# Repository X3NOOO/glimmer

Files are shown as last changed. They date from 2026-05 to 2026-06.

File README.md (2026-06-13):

# Glimmer
Glimmer is an [WLED](https://github.com/wled/WLED) controller board. It supports all the most common LED strip voltages over 6.3mm jack and 5V over USB-C, audio reactivity, IR control, and driving two separate data channels at once.

<details>
<summary>Photos</summary>

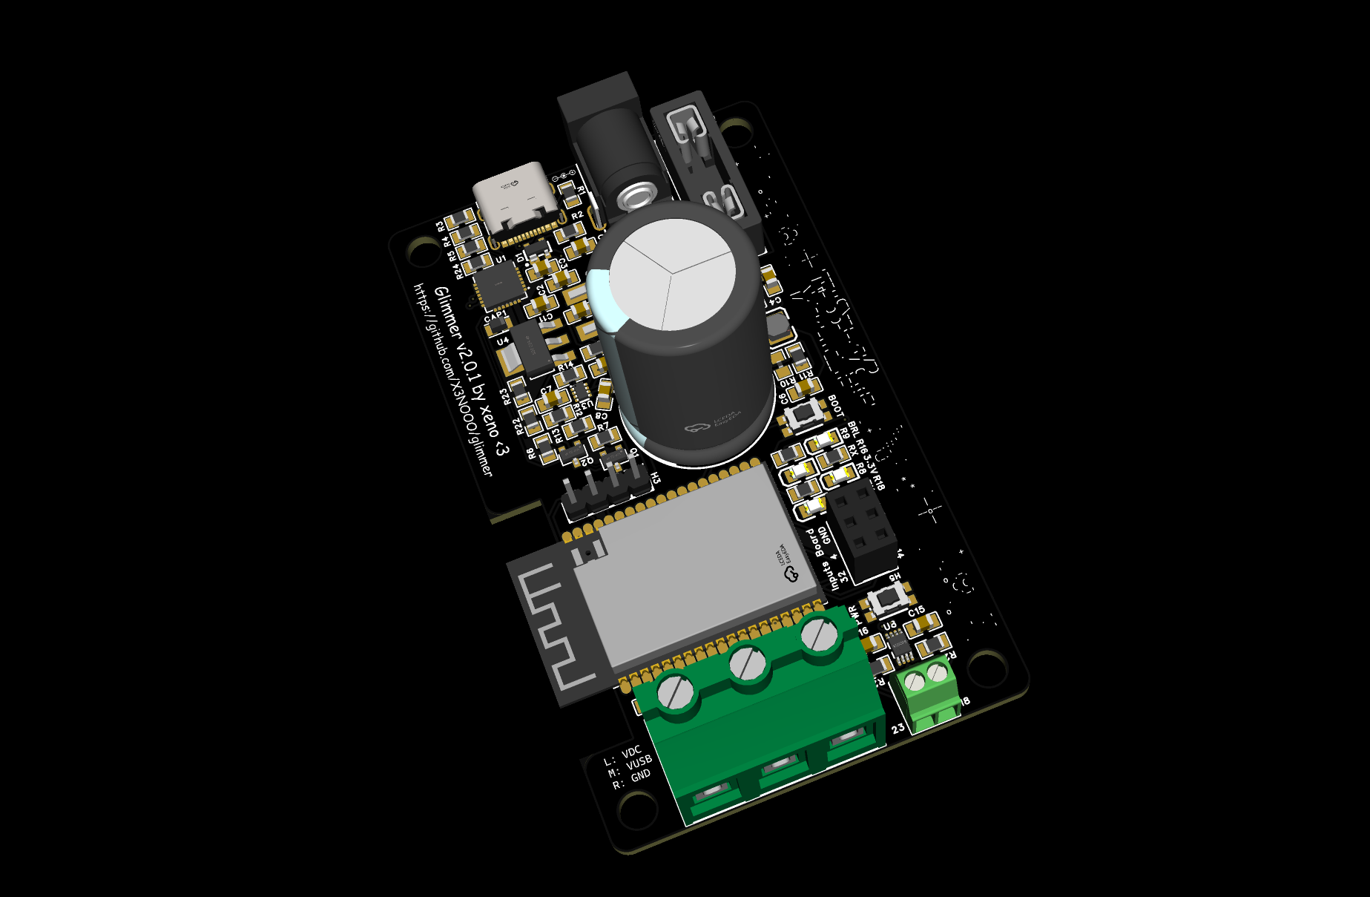
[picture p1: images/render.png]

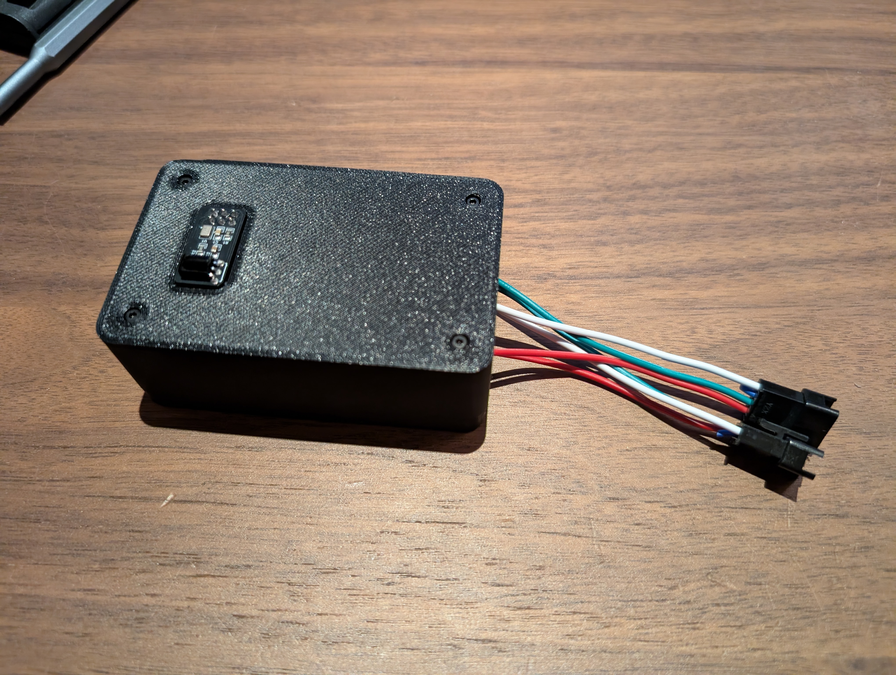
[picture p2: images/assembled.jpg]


[schematics.pdf](/images/schematics.pdf)

</details>

## OSHWLab Stars 2026
The project had to be remade in EasyEDA in order to be submitted to the OSHWLab Stars competition. I'm not the biggest fan of the program, but it is what it is.

If you like the project feel free to check out it's OSHWLab page and maybe even leave a like if you're generous like that.

Link to the project over there: https://oshwlab.com/x3no/project_caxlifbu

## Software
The controller is meant to run under WLED. Check their docs for info about configuration and flashing.
Website: https://kno.wled.ge/
Github: https://github.com/WLED/WLED

There is an USB autoflashing circuitry present on the board, but you can use the UART port as well. If you do want to do it you should desolder the 0-ohm R22 and R22 resistors - they bridge the USB-UART controller with the ESP32.

If you want to use WLED-MM a platformio compilation environment is available [here](https://gist.github.com/X3NOOO/2119d469b6a600acc29e1caa4ec98841).

### UART LEDs

If the TX/RX LEDs are not flashing when talking with the board via USB your CP2102N didn't come with TXT and RXT enabled by default. You can change that using the [Simplicity Studio 5](https://www.silabs.com/software-and-tools/simplicity-studio/simplicity-studio-version-5). Download it, connect the board, and change the GPIO settings from GPIO to TXT and RXT. Doing this is not neccesary for the board to work though.

## Usage
Flashed your board with WLED? Good, now it's the time to wire it up. The first thing to do is to place a properly rated fuse into the fuse holder. The [3557-2 fuseholder](https://www.keyelco.com/userAssets/file/K75p47.pdf) takes both standard and mini automotive fuses. You can calculate the fuse value using the WLED calculator. The big screw terminal is responsible for power delivery. When holding your controller with the USB port up and facing you:
- The first hole is VDC, it's the barrel jack input, except it's fused via the fuse you just put in.
- The second hole is VUSB, it's the same power your USB port supplies. There is an 2A polyfuse placed on it's line, so that's the limit on the power you can pull through it.
- The third hole is GND.

Then, there is the smaller screw terminal. It is used to communicate with your LEDs and houses the data lines. Both of them are levelshifted to 5V. The one on the left is mapped to your ESP32's GPIO23 and the right one is GPIO18.

Now you connect the inputs board. Place some doublesided tape on the back of it and secure it in the cutout on the shell. Wire the connector 1:1, you can check the pinout if you're not sure if you're doing it right.

## Case
The .stl files of the enclosure are available in the Releases tab.

## Pricing
Prices at JLCPCB.

### Controller
- $160: Price for 2 assembled and 3 bare PCBs. All in black.
- $100: Price for 2 assembled and 3 bare PCBs w/o the ESP32 which forces you to pick standard assembly.
- $30: Price for 2+3 with most of the extended components excluded if you're willing to source and solder them yourself.

### Inputs board
Header is not soldered in any of the variants.
- $70: 2 assembled and 3 bare ones.
- $20: 2 assembled and 3 bare ones w/o the microphone as it forces standard assembly.

### Shell
- Up to $10: 1 bottom + 1 top. 

### Additional
- 4x >33mm M2 screws.
- 4x M2 threaded M2 insert nuts. Length=2mm, OD=4mm.
- A bit of double sided tape if your Inputs Board doesn't hold in place.

## Get it
All the files necessary to get the board made at JLCPCB are available in the Releases tab. They include all the components, so you can expect a to see a high price if you use them as they are. You can tweak the assembly components after uploading the BOM to the website to lower the price.

## IMPORTANT
I am not an engineer - the PCB works, but I cannot guarantee it will not burn your house down. I do not take any responsibility for y'all being silly.

## Sidenotes
- Thank you to the (unfortunately dead) [yawl controller](https://github.com/lizardsystems/yawl-controller) project - I stole your levelshifter.

- Thank you to the creators of the [OSHWLab Stars](https://oshwlab.com/activities/stars2026) competition for making it possible to get this board manufactured in a reasonable price.

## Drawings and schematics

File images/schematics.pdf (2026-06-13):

# Power Input

## Barrel jack

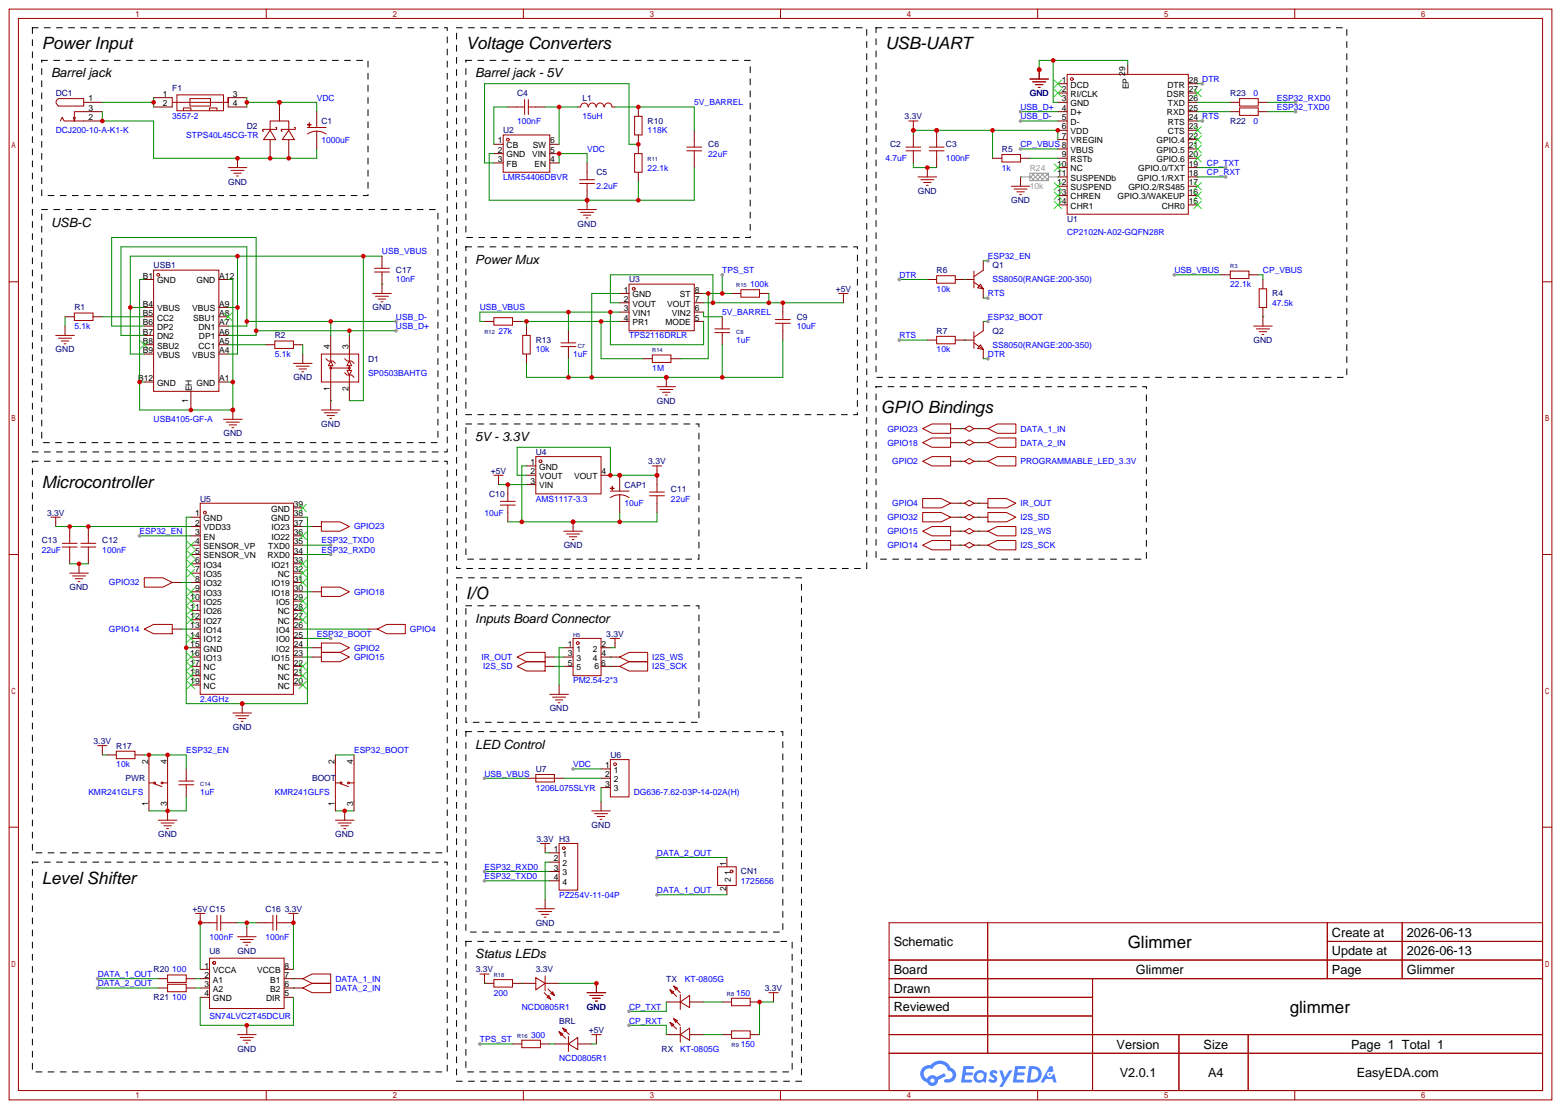
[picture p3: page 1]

Schematic | Glimmer | Create at | 2026-06-13

Update at | 2026-06-13

Board | Glimmer | Page | Glimmer
Drawn | | glimmer
Reviewed

Version | Size | Page 1 Total 1
V2.0.1 | A4 | EasyEDA.com

# Connector

# IR Receiver

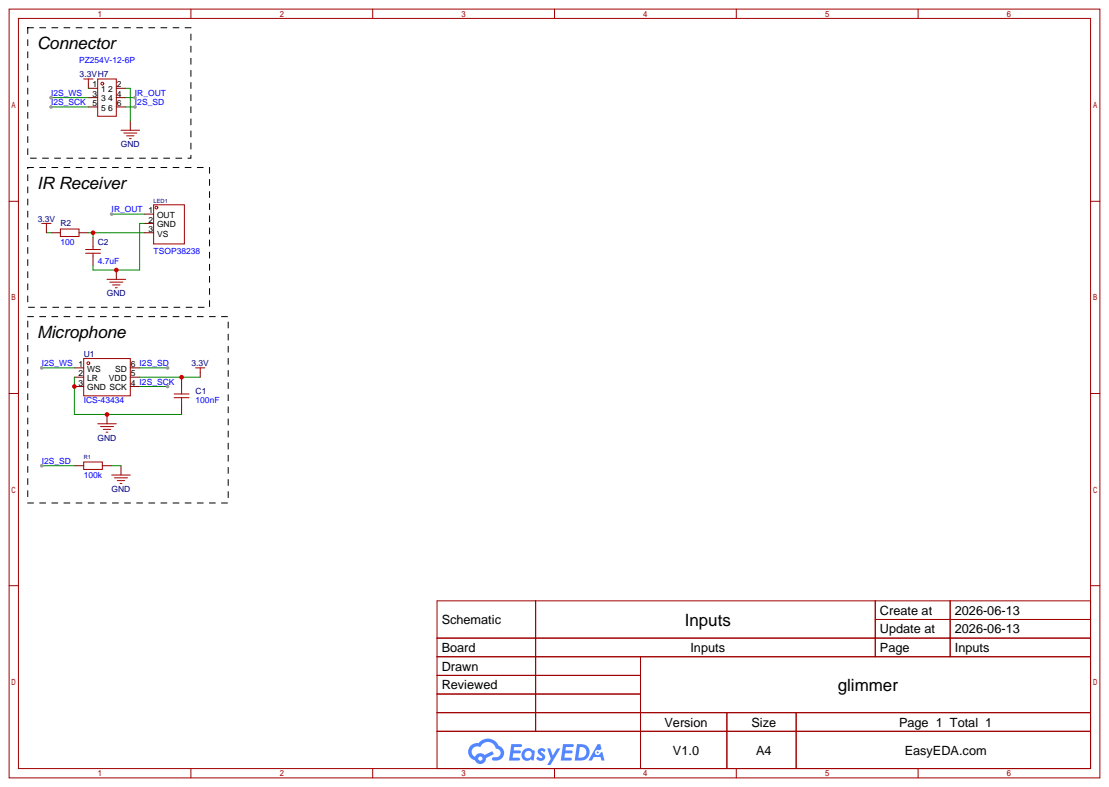
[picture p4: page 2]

Schematic | Inputs | Create at | 2026-06-13

Update at | 2026-06-13

Board | Inputs | Page | Inputs
Drawn | | glimmer
Reviewed

Version | Size | Page 1 Total 1
V1.0 | A4 | EasyEDA.com

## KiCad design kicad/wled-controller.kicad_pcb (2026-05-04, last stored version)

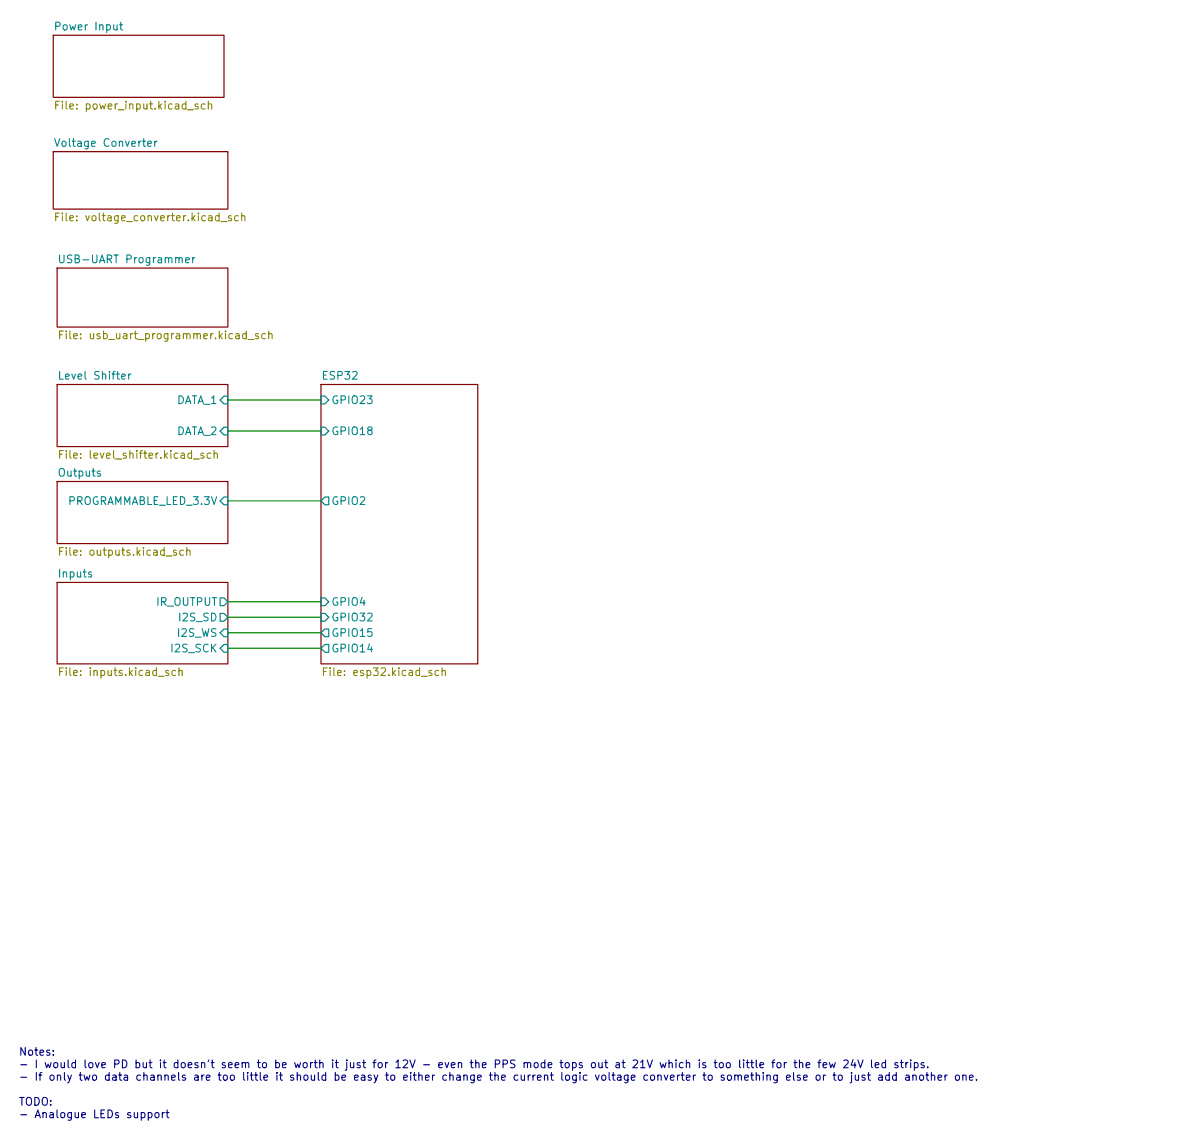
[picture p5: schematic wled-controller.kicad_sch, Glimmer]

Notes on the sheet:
Notes: - I would love PD but it doesn't seem to be worth it just for 12V - even the PPS mode tops out at 21V which is too little for the few 24V led strips. - If only two data channels are too little it should be easy to either change the current logic voltage converter to something else or to just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

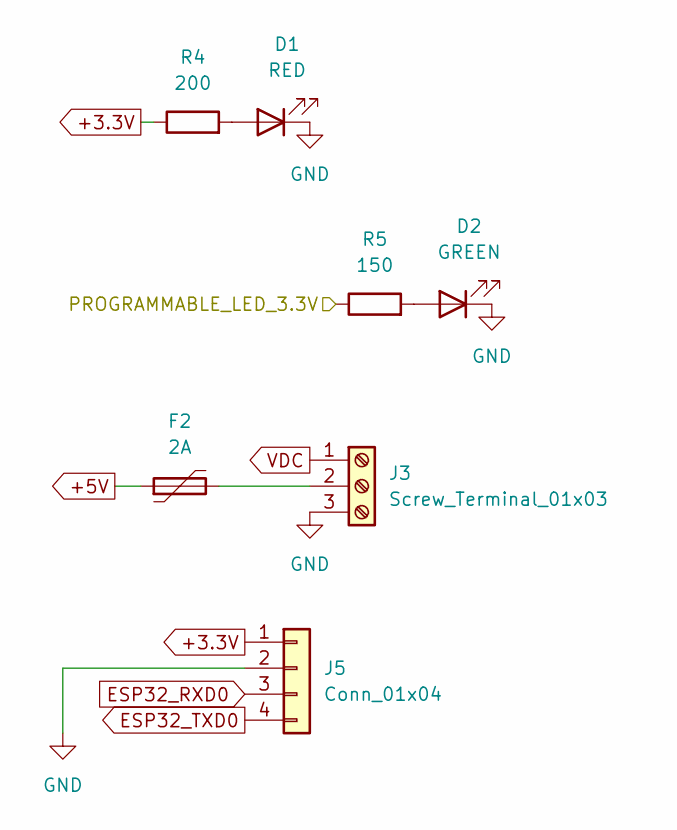
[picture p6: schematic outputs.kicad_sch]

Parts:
D1: RED; LED_0805_2012Metric_Pad1.15x1.40mm_HandSolder
D2: GREEN; LED_0805_2012Metric_Pad1.15x1.40mm_HandSolder
F2: 2A; 1206L075SLYR
J3: Screw_Terminal_01x03; TerminalBlock_TE_282834-3_1x03_P2.54mm_Horizontal
J5: Conn_01x04; NS-Tech_Grove_1x04_P2mm_Vertical
R4: 200; R_0805_2012Metric_Pad1.20x1.40mm_HandSolder
R5: 150; R_0805_2012Metric_Pad1.20x1.40mm_HandSolder

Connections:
+3.3V: J5.1, R4.1; also elsewhere on the board
+5V: F2.1; also elsewhere on the board
/ESP32/GPIO2: R5.1; also elsewhere on the board
ESP32_RXD0: J5.3; also elsewhere on the board
ESP32_TXD0: J5.4; also elsewhere on the board
GND: D1.1 (K), D2.1 (K), J3.3, J5.2; also elsewhere on the board
unnamed: D1.2 (A), R4.2
unnamed: D2.2 (A), R5.2
unnamed: F2.2, J3.2
VDC: J3.1; also elsewhere on the board

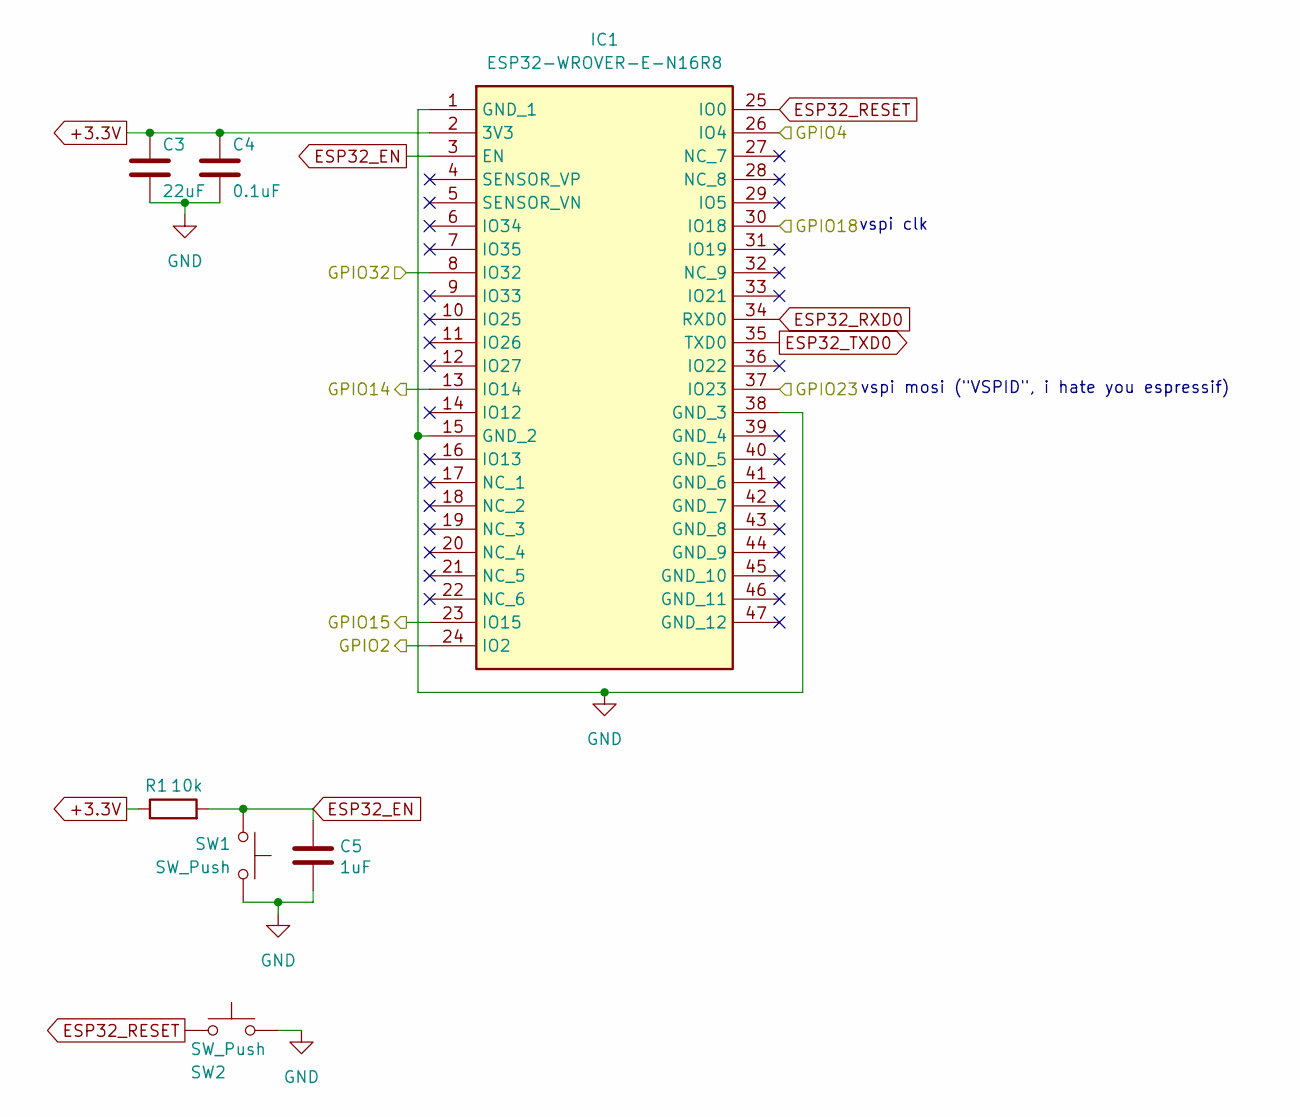
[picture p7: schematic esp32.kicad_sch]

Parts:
C3: 22uF; C_0805_2012Metric_Pad1.18x1.45mm_HandSolder
C4: 0.1uF; C_0805_2012Metric_Pad1.18x1.45mm_HandSolder
C5: 1uF; C_0805_2012Metric_Pad1.18x1.45mm_HandSolder
IC1: ESP32-WROVER-E-N16R8; ESP32WROVEREN16R8; Manufacturer_Part_Number ESP32-WROVER-E-N16R8; Mouser Part Number 356-ESP32WRVE22864PC
R1: 10k; R_0805_2012Metric_Pad1.20x1.40mm_HandSolder
SW1, SW2: SW_Push; SW_Push_1P1T_NO_CK_KMR2

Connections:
+3.3V: C3.1, C4.1, IC1.2 (3V3), R1.1; also elsewhere on the board
/ESP32/GPIO2: IC1.24 (IO2); also elsewhere on the board
/ESP32/GPIO4: IC1.26 (IO4); also elsewhere on the board
/ESP32/GPIO14: IC1.13 (IO14); also elsewhere on the board
/ESP32/GPIO15: IC1.23 (IO15); also elsewhere on the board
/ESP32/GPIO18: IC1.30 (IO18); also elsewhere on the board
/ESP32/GPIO23: IC1.37 (IO23); also elsewhere on the board
/ESP32/GPIO32: IC1.8 (IO32); also elsewhere on the board
ESP32_EN: C5.1, IC1.3 (EN), R1.2, SW1.1; also elsewhere on the board
ESP32_RESET: IC1.25 (IO0), SW2.1; also elsewhere on the board
ESP32_RXD0: IC1.34 (RXD0); also elsewhere on the board
ESP32_TXD0: IC1.35 (TXD0); also elsewhere on the board
GND: C3.2, C4.2, C5.2, IC1.1 (GND_1), IC1.15 (GND_2), IC1.38 (GND_3), SW1.2, SW2.2; also elsewhere on the board

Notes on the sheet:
vspi mosi ("VSPID", i hate you espressif)
vspi clk

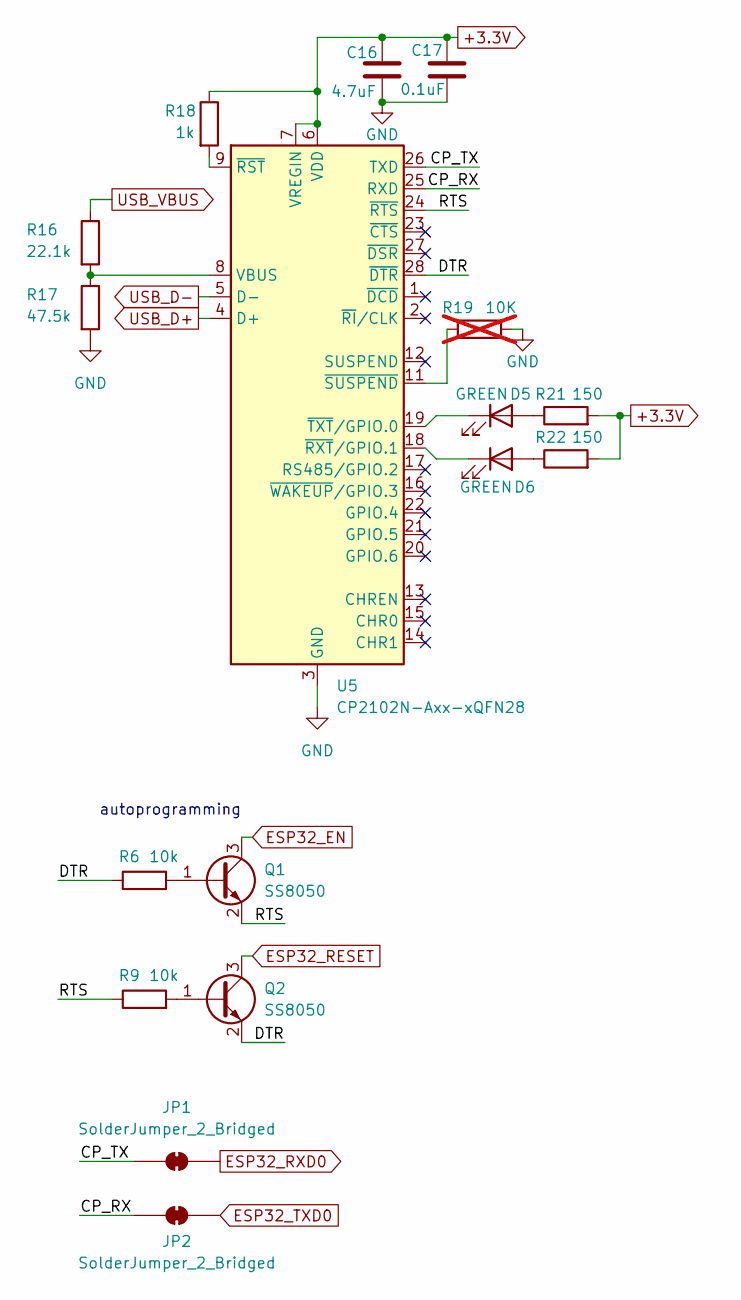
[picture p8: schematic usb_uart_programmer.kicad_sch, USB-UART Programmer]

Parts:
C16: 4.7uF; C_0805_2012Metric_Pad1.18x1.45mm_HandSolder
C17: 0.1uF; C_0805_2012Metric_Pad1.18x1.45mm_HandSolder
D5, D6: GREEN; LED_0805_2012Metric_Pad1.15x1.40mm_HandSolder
JP1, JP2: SolderJumper_2_Bridged; SolderJumper-2_P1.3mm_Open_TrianglePad1.0x1.5mm
Q1, Q2: SS8050; SOT-23
R6, R9: 10k; R_0805_2012Metric_Pad1.20x1.40mm_HandSolder
R16: 22.1k; R_0805_2012Metric_Pad1.20x1.40mm_HandSolder
R17: 47.5k; R_0805_2012Metric_Pad1.20x1.40mm_HandSolder
R18: 1k; R_0805_2012Metric_Pad1.20x1.40mm_HandSolder
R19: 10K; R_0805_2012Metric_Pad1.20x1.40mm_HandSolder; not fitted
R21, R22: 150; R_0805_2012Metric_Pad1.20x1.40mm_HandSolder
U5: CP2102N-Axx-xQFN28; QFN-28-1EP_5x5mm_P0.5mm_EP3.35x3.35mm

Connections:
+3.3V: C16.1, C17.1, R18.1, R21.2, R22.2, U5.6 (VDD), U5.7 (VREGIN); also elsewhere on the board
/USB-UART Programmer/CP_RX: JP2.1 (A), U5.25 (RXD)
/USB-UART Programmer/CP_TX: JP1.1 (A), U5.26 (TXD)
/USB-UART Programmer/DTR: Q2.2 (E), R6.1, U5.28 (~DTR)
/USB-UART Programmer/RTS: Q1.2 (E), R9.1, U5.24 (~RTS)
ESP32_EN: Q1.3 (C); also elsewhere on the board
ESP32_RESET: Q2.3 (C); also elsewhere on the board
ESP32_RXD0: JP1.2 (B); also elsewhere on the board
ESP32_TXD0: JP2.2 (B); also elsewhere on the board
GND: C16.2, C17.2, R17.2, R19.2, U5.3 (GND), U5.29 (GND); also elsewhere on the board
unnamed: D5.2 (A), R21.1
unnamed: D5.1 (K), U5.19 (~TXT/GPIO.0)
unnamed: D6.2 (A), R22.1
unnamed: D6.1 (K), U5.18 (~RXT/GPIO.1)
unnamed: Q1.1 (B), R6.2
unnamed: Q2.1 (B), R9.2
unnamed: R16.2, R17.1, U5.8 (VBUS)
unnamed: R18.2, U5.9 (~RST)
unnamed: R19.1, U5.11 (~SUSPEND)
USB_D+: U5.4 (D+); also elsewhere on the board
USB_D-: U5.5 (D-); also elsewhere on the board
USB_VBUS: R16.1; also elsewhere on the board

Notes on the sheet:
autoprogramming

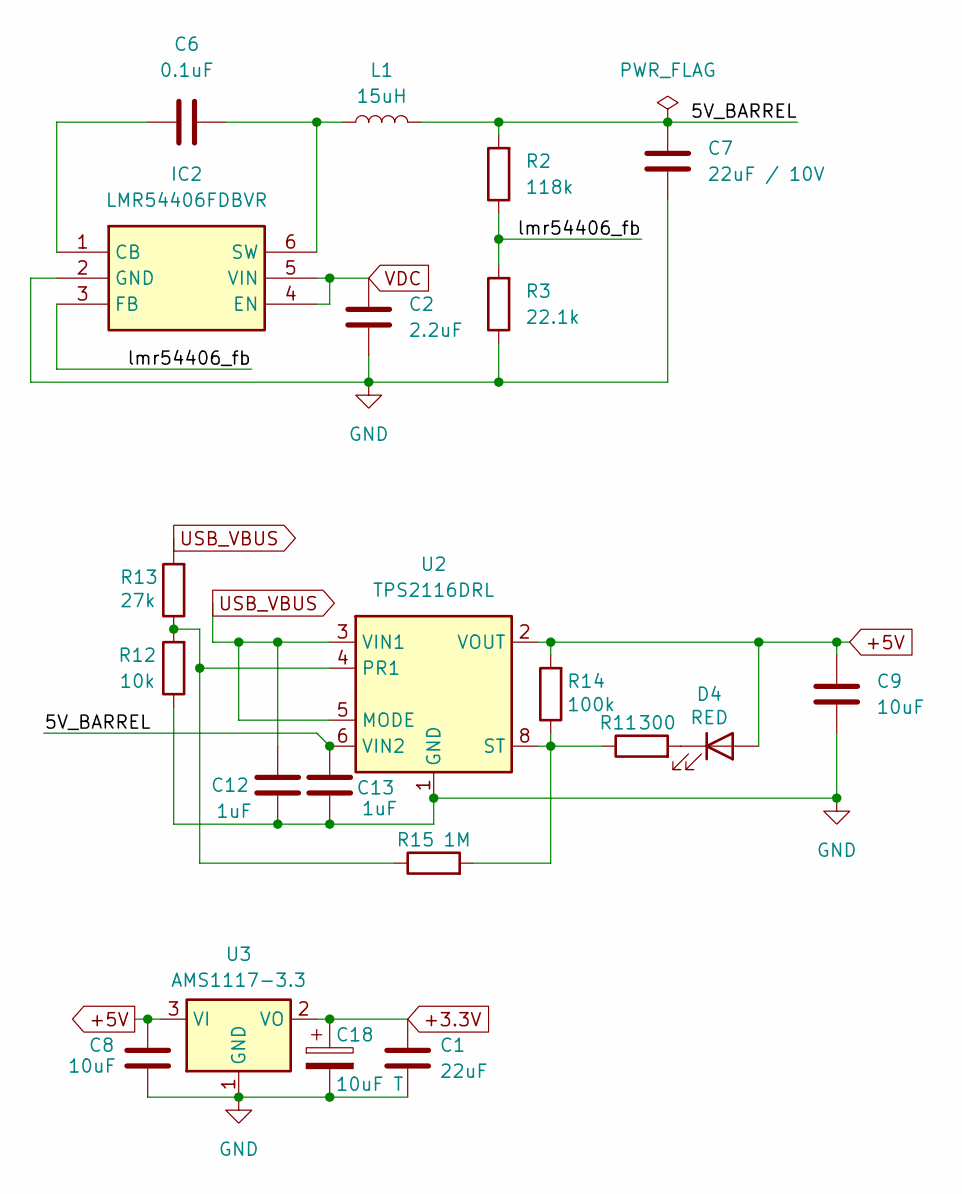
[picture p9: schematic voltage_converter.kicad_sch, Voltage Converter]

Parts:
C1: 22uF; C_0805_2012Metric_Pad1.18x1.45mm_HandSolder
C2: 2.2uF; C_0805_2012Metric_Pad1.18x1.45mm_HandSolder
C6: 0.1uF; C_0805_2012Metric_Pad1.18x1.45mm_HandSolder
C7: 22uF / 10V; C_0805_2012Metric_Pad1.18x1.45mm_HandSolder
C8, C9: 10uF; C_0805_2012Metric_Pad1.18x1.45mm_HandSolder
C12, C13: 1uF; C_0805_2012Metric_Pad1.18x1.45mm_HandSolder
C18: 10uF T; CP_EIA-2012-12_Kemet-R_HandSolder
D4: RED; LED_0805_2012Metric_Pad1.15x1.40mm_HandSolder
IC2: LMR54406FDBVR; SOT95P280X145-6N; Manufacturer_Part_Number LMR54406FDBVR; Mouser Part Number 595-LMR54406FDBVR
L1: 15uH; VLS3015
R2: 118k; R_0805_2012Metric_Pad1.20x1.40mm_HandSolder
R3: 22.1k; R_0805_2012Metric_Pad1.20x1.40mm_HandSolder
R11: 300; R_0805_2012Metric_Pad1.20x1.40mm_HandSolder
R12: 10k; R_0805_2012Metric_Pad1.20x1.40mm_HandSolder
R13: 27k; R_0805_2012Metric_Pad1.20x1.40mm_HandSolder
R14: 100k; R_0805_2012Metric_Pad1.20x1.40mm_HandSolder
R15: 1M; R_0805_2012Metric_Pad1.20x1.40mm_HandSolder
U2: TPS2116DRL; SOT-583-8
U3: AMS1117-3.3; SOT-223-3_TabPin2

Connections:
+3.3V: C1.1, C18.1, U3.2 (VO); also elsewhere on the board
+5V: C8.1, C9.1, D4.2 (A), R14.2, U2.2 (VOUT), U2.7 (VOUT), U3.3 (VI); also elsewhere on the board
/Voltage Converter/5V_BARREL: C7.1, C13.1, L1.2, R2.2, U2.6 (VIN2)
/Voltage Converter/lmr54406_fb: IC2.3 (FB), R2.1, R3.2
GND: C1.2, C2.2, C7.2, C8.2, C9.2, C12.2, C13.2, C18.2, IC2.2 (GND), R3.1, R12.1, U2.1 (GND), U3.1 (GND); also elsewhere on the board
unnamed: D4.1 (K), R11.2
unnamed: C6.1, IC2.1 (CB)
unnamed: C6.2, IC2.6 (SW), L1.1
unnamed: R12.2, R13.1, R15.1, U2.4 (PR1)
unnamed: R11.1, R14.1, R15.2, U2.8 (ST)
USB_VBUS: C12.1, R13.2, U2.3 (VIN1), U2.5 (MODE); also elsewhere on the board
VDC: C2.1, IC2.4 (EN), IC2.5 (VIN); also elsewhere on the board

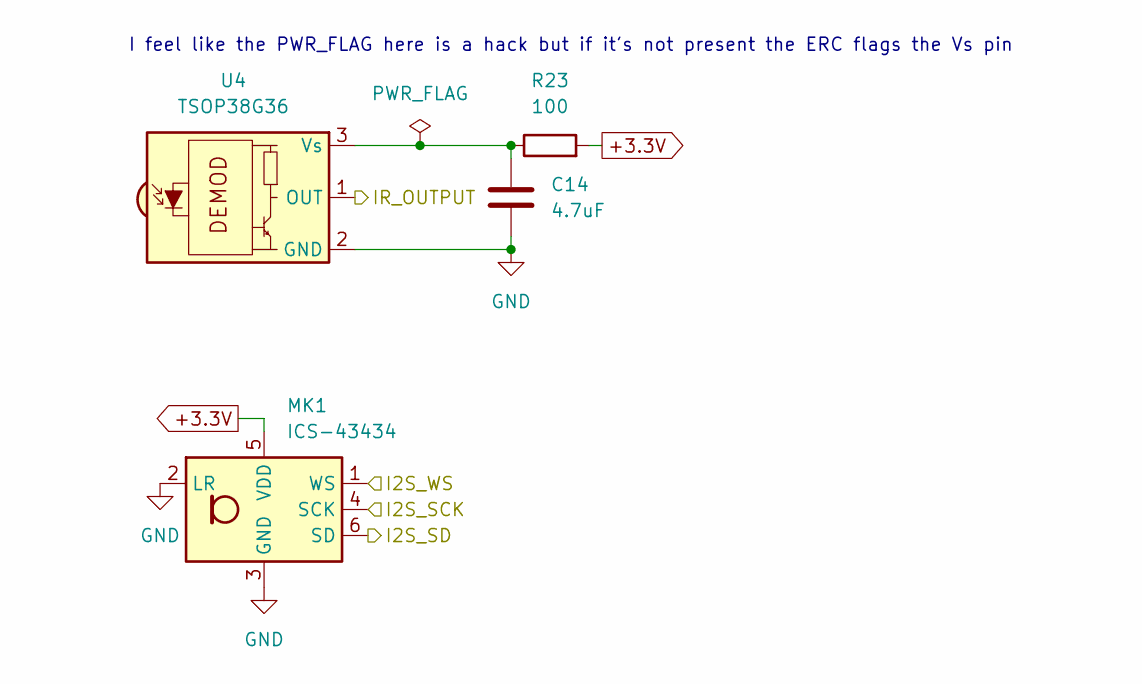
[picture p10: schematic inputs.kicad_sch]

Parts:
C14: 4.7uF; C_0805_2012Metric_Pad1.18x1.45mm_HandSolder
MK1: ICS-43434; PinHeader_2x03_P1.00mm_Vertical
R23: 100; R_0805_2012Metric_Pad1.20x1.40mm_HandSolder
U4: TSOP38G36; PinHeader_1x03_P1.00mm_Vertical

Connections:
+3.3V: MK1.5 (VDD), R23.2; also elsewhere on the board
/ESP32/GPIO4: U4.1 (OUT); also elsewhere on the board
/ESP32/GPIO14: MK1.4 (SCK); also elsewhere on the board
/ESP32/GPIO15: MK1.1 (WS); also elsewhere on the board
/ESP32/GPIO32: MK1.6 (SD); also elsewhere on the board
GND: C14.2, MK1.2 (LR), MK1.3 (GND), U4.2 (GND); also elsewhere on the board
unnamed: C14.1, R23.1, U4.3 (Vs)

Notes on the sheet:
I feel like the PWR_FLAG here is a hack but if it's not present the ERC flags the Vs pin

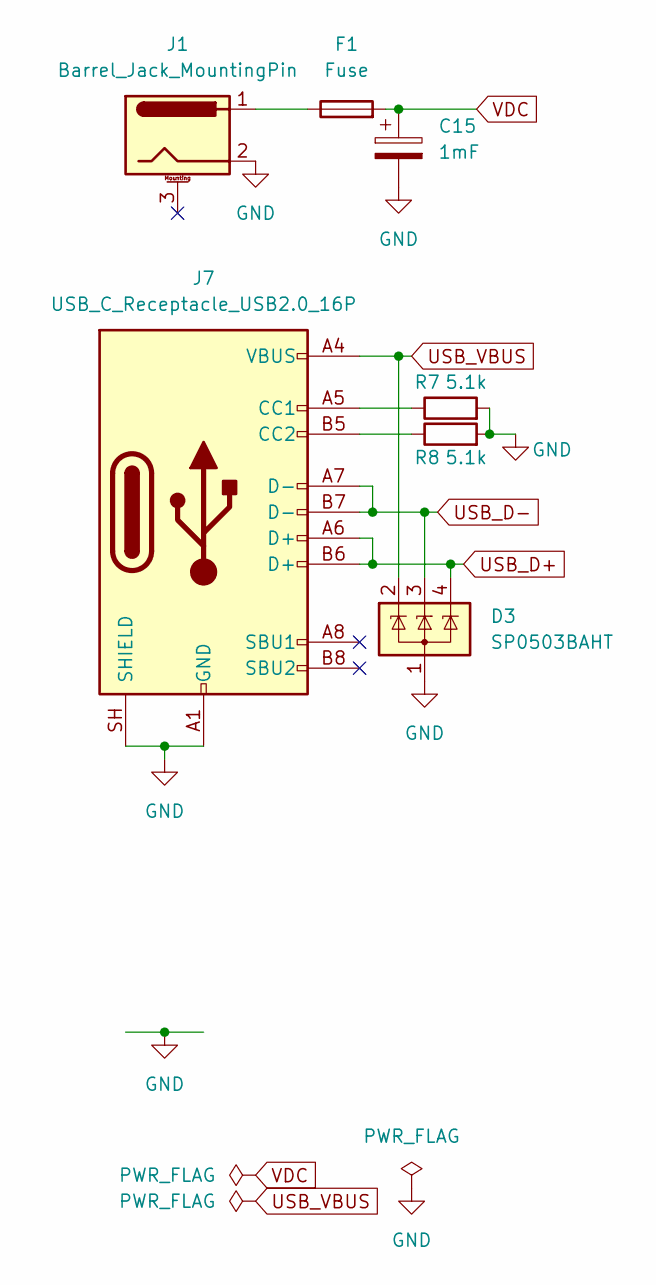
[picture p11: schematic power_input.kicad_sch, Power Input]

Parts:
C15: 1mF; CP_Radial_D16.0mm_P7.50mm
D3: SP0503BAHT; SOT-143
F1: Fuse; 3557-2
J1: Barrel_Jack_MountingPin; BarrelJack_GCT_DCJ200-10-A_Horizontal
J7: USB_C_Receptacle_USB2.0_16P; USB_C_Receptacle_GCT_USB4105-xx-A_16P_TopMnt_Horizontal
R7, R8: 5.1k; R_0805_2012Metric_Pad1.20x1.40mm_HandSolder

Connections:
GND: C15.2, D3.1 (A), J1.2, J7.A1 (GND), J7.A12 (GND), J7.B1 (GND), J7.B12 (GND), J7.SH (SHIELD), R7.2, R8.2; also elsewhere on the board
unnamed: F1.1, J1.1
unnamed: J7.A5 (CC1), R7.1
unnamed: J7.B5 (CC2), R8.1
USB_D+: D3.4 (K), J7.A6 (D+), J7.B6 (D+); also elsewhere on the board
USB_D-: D3.3 (K), J7.A7 (D-), J7.B7 (D-); also elsewhere on the board
USB_VBUS: D3.2 (K), J7.A4 (VBUS), J7.A9 (VBUS), J7.B4 (VBUS), J7.B9 (VBUS); also elsewhere on the board
VDC: C15.1, F1.2; also elsewhere on the board

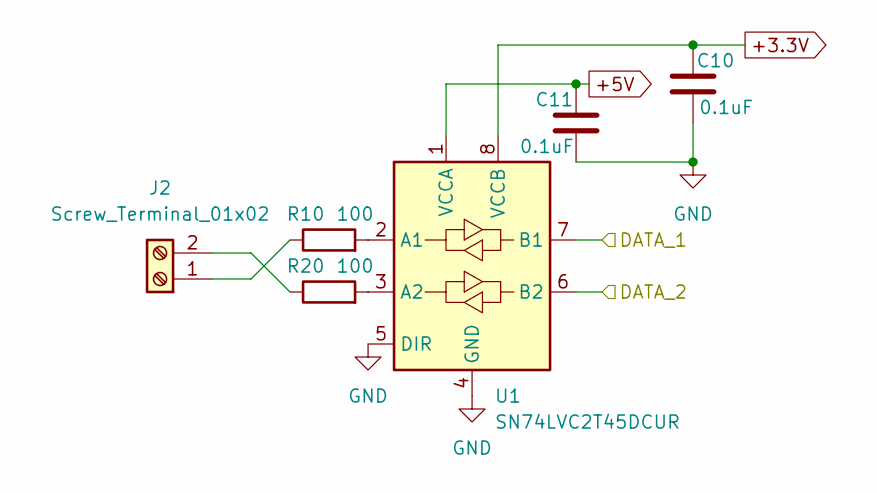
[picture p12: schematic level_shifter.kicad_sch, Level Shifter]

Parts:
C10, C11: 0.1uF; C_0805_2012Metric_Pad1.18x1.45mm_HandSolder
J2: Screw_Terminal_01x02; TerminalBlock_TE_282834-2_1x02_P2.54mm_Horizontal
R10, R20: 100; R_0805_2012Metric_Pad1.20x1.40mm_HandSolder
U1: SN74LVC2T45DCUR; VSSOP-8_2.3x2mm_P0.5mm

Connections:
+3.3V: C10.1, U1.8 (VCCB); also elsewhere on the board
+5V: C11.1, U1.1 (VCCA); also elsewhere on the board
/ESP32/GPIO18: U1.6 (B2); also elsewhere on the board
/ESP32/GPIO23: U1.7 (B1); also elsewhere on the board
GND: C10.2, C11.2, U1.4 (GND), U1.5 (DIR); also elsewhere on the board
unnamed: J2.1, R10.1
unnamed: J2.2, R20.1
unnamed: R10.2, U1.2 (A1)
unnamed: R20.2, U1.3 (A2)

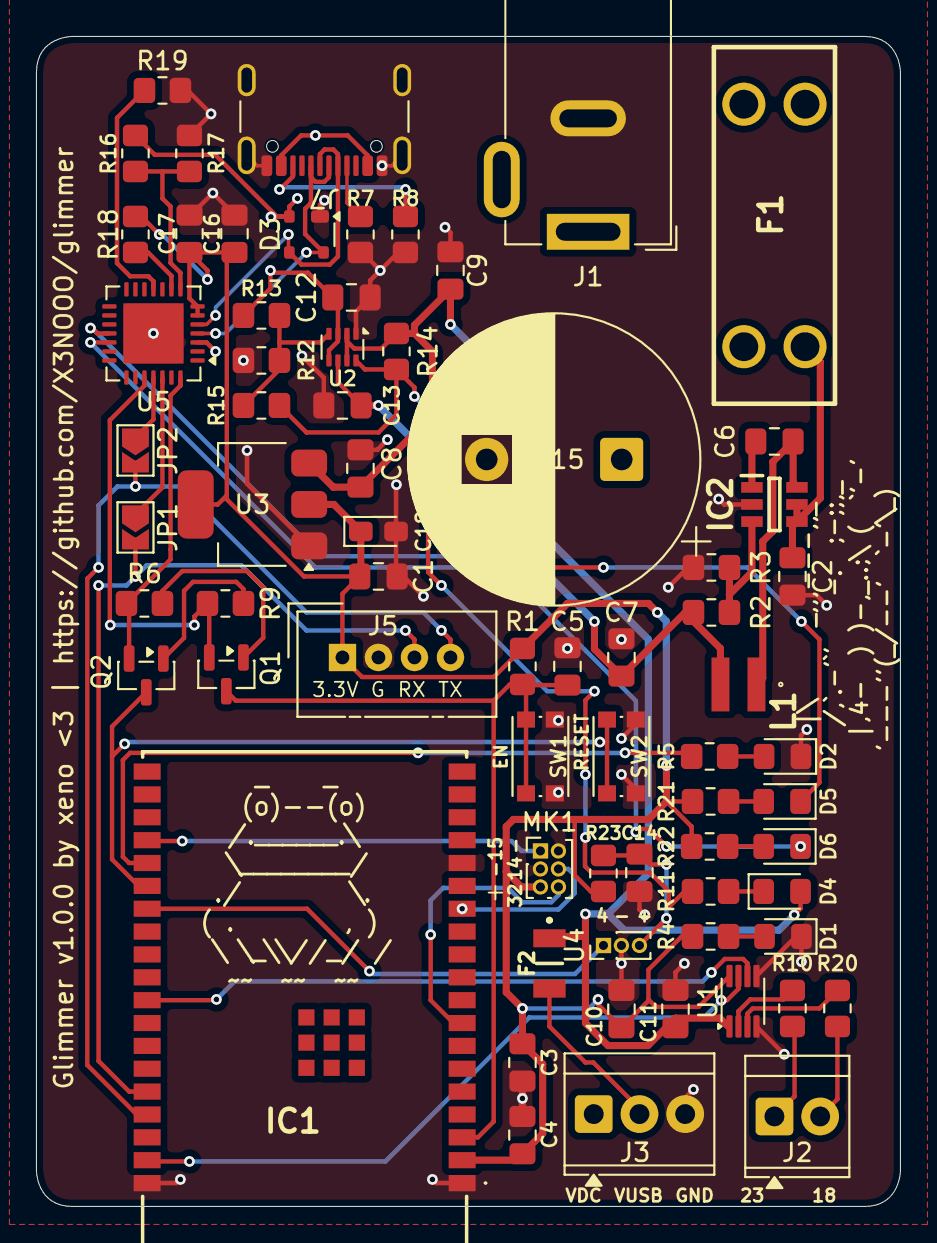
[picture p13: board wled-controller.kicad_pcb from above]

Board: 4 copper layers, 48.0 x 65.0 mm, 69 parts (0 on the bottom side), 49 nets.
